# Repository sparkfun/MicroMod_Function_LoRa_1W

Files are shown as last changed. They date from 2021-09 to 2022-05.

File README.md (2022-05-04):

SparkFun MicroMod LoRa Function Board
========================================

SparkFun MicroMod LoRa Function Board (https://www.sparkfun.com/products/18573)

[*SparkFun MicroMod LoRa Function Board (DEV-18573)*](https://www.sparkfun.com/products/18573)

The SparkFun MicroMod LoRa Function Board provides LoRA and LoRaWAN capabilities to your MicroMod project. It is intended to be used in conjunction with a MicroMod Processor Board and a MicroMod Main Board, which provides the electrical interface between a processor board and the Function Board(s).

The LoRa Function Board utilizes the 915M30S LoRa module from EBYTE, which is a 1W (30dBm) transceiver based around the SX1276 from Semtech. There is a robust edge mount RP-SMA connector for large LoRa (915MHz) antennas; with modification, a U.FL connector is also available. We've successfully tested a 12 miles line-of-sight transmission with this module (test was performed under ideal conditions; individual user results may vary).

With the MicroMod standardization, users no longer need to cross-reference schematics with datasheets, while fumbling around with jumper wires. Simply, match up the function board's M.2 edge connector to the slot of the M.2 connector on the main board and secure the function board with screws.

Repository Contents
-------------------

* **/Firmware** - Arduino example code from the tutorial
* **/Hardware** - Eagle design files (.brd, .sch)
* **/Hardware/Production** - Production panel files (.brd)

Documentation
--------------

* **[E19-915M30S Datasheet](https://github.com/sparkfun/MicroMod_Function_LoRa_1W/blob/main/Documents/E19-915M30S_Usermanual_EN_v1.20.pdf)** - Datasheet for the LoRa module
  * **[SX1276 Datasheet](https://cdn.sparkfun.com/assets/7/7/3/2/2/SX1276_Datasheet.pdf)** - Datasheet for the transceiver the LoRa module is based on
* **[Hookup Guide](https://learn.sparkfun.com/tutorials/1996)** - Basic hookup guide
* **[SparkFun External EEPROM Arduino Library](https://github.com/sparkfun/SparkFun_External_EEPROM_Arduino_Library)** - Arduino library for the EEPROM
* **[RadioLib Arduino Library](https://github.com/jgromes/RadioLib)** - Arduino library for peer-to-peer communication with the LoRa module

Product Versions
----------------

* [DEV-18573](https://www.sparkfun.com/products/18573)- Initial release

Version History
---------------

* v1.0 - Initial Release

License Information
-------------------

This product is _**open source**_! 

Please review the LICENSE.md file for license information. 

If you have any questions or concerns on licensing, please contact technical support on our [SparkFun forums](https://forum.sparkfun.com/viewforum.php?f=152).

Distributed as-is; no warranty is given.

- Your friends at SparkFun.

_<COLLABORATION CREDIT>_

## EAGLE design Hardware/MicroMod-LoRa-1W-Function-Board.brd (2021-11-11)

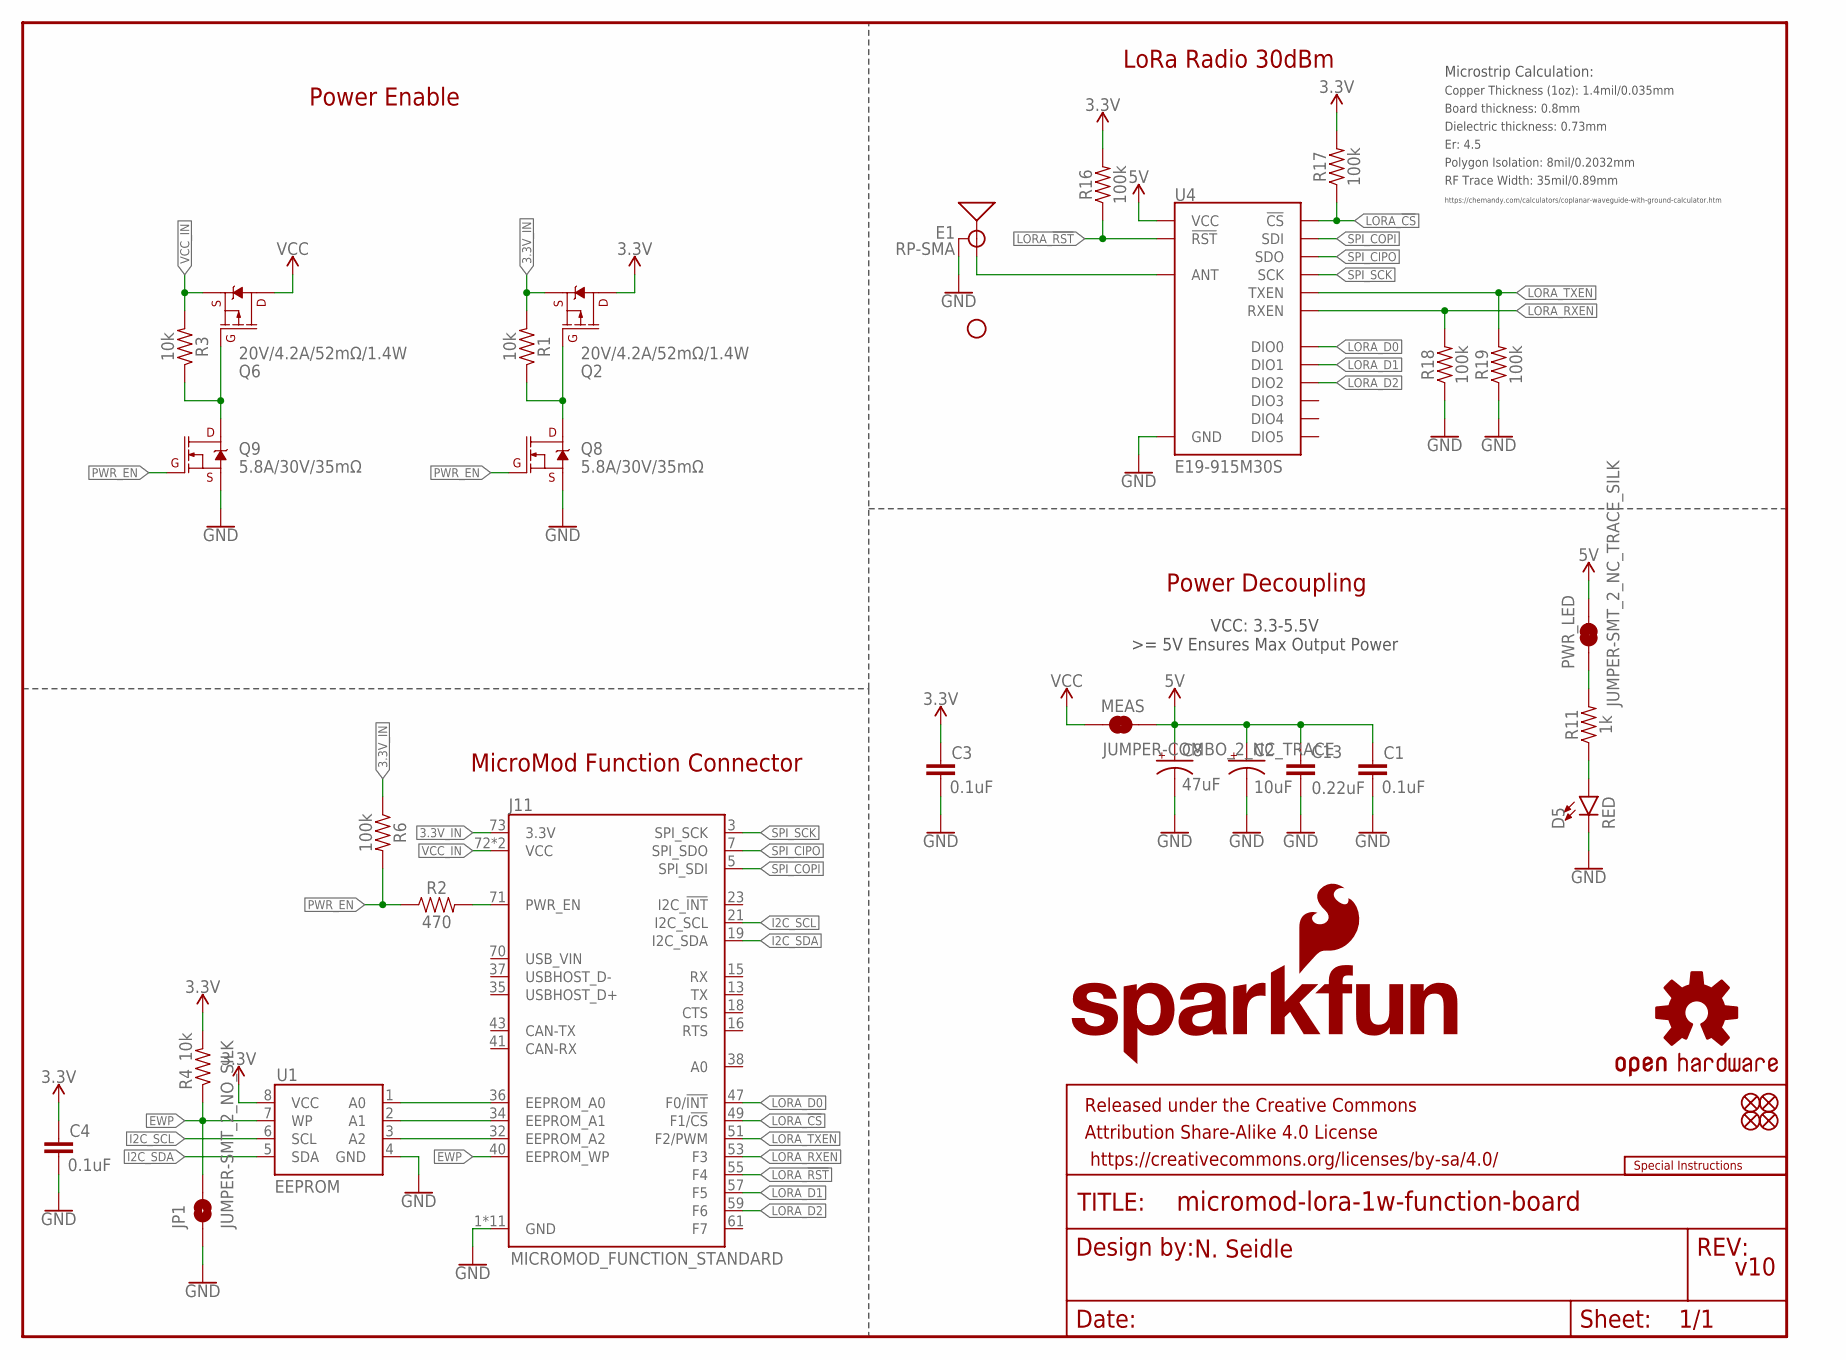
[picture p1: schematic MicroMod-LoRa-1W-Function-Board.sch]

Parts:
C1, C3, C4: 0.1uF; 0603
C2: 10uF; EIA3216
C8: 47uF; EIA3528
C13: 0.22uF; 0603
D5: RED; LED-0603
E1: RP-SMA; SMA-EDGE-SMD
FD1, FD2, FD3, FD4: FIDUCIALUFIDUCIAL; FIDUCIAL-MICRO
FRAME2: FRAME-LETTER; CREATIVE_COMMONS
H1: STAND-OFF
J11: MICROMOD_FUNCTION_STANDARD; M.2-CARD-E-22_FUNCTION_STANDARD
JP1: JUMPER-SMT_2_NO_SILK; SMT-JUMPER_2_NO_SILK
LOGO1: SFE_LOGO_NAME_FLAME.1_INCH; SFE_LOGO_NAME_FLAME_.1
LOGO2: SPECIAL_INSTRUCTIONS-ORDERING; ORDERING_INSTRUCTIONS
LOGO3: OSHW-LOGOMINI; OSHW-LOGO-MINI
MEAS: JUMPER-COMBO_2_NC_TRACE; COMBO-JUMPER_2_NC_TRACE
PWR_LED: JUMPER-SMT_2_NC_TRACE_SILK; SMT-JUMPER_2_NC_TRACE_SILK
Q2, Q6: 20V/4.2A/52mΩ/1.4W; SOT23-3
Q8, Q9: 5.8A/30V/35mΩ; SOT23-3
R1, R3, R4: 10k; 0603
R2: 470; 0603
R6, R16, R17, R18, R19: 100k; 0603
R11: 1k; 0603
U1: EEPROM; SO08
U4: E19-915M30S; E19-915MS1W

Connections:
3.3V: C3.1, C4.1, Q2.3 (D), R4.2, R16.2, R17.2, U1.8 (VCC)
3.3V_IN: J11.73 (3.3V), Q2.2 (S), R1.2, R6.1
5V: C1.1, C2.+, C8.A (+), C13.1, MEAS.2, MEAS.4 (2), PWR_LED.2, U4.11 (VCC)
A0: J11.36 (EEPROM_A0), U1.1 (A0)
A1: J11.34 (EEPROM_A1), U1.2 (A1)
A2: J11.32 (EEPROM_A2), U1.3 (A2)
EWP: J11.40 (EEPROM_WP), JP1.2, R4.1, U1.7 (WP)
GND: C1.2, C2.-, C3.2, C4.2, C8.C (-), C13.2, D5.C, E1.GND@0 (GND), E1.GND@1 (GND), J11.1 (GND), J11.33 (GND), J11.39 (GND), J11.45 (GND), J11.75 (GND), J11.GND1 (GND), J11.GND2 (GND), J11.GND3 (GND), J11.GND4 (GND), J11.GND5 (GND), J11.GND6 (GND), JP1.1, Q8.2 (S), Q9.2 (S), R18.1, R19.1, U1.4 (GND), U4.1 (GND), U4.9 (GND), U4.10 (GND), U4.18 (GND), U4.20 (GND), U4.21 (GND), U4.22 (GND)
I2C_SCL: J11.21 (I2C_SCL), U1.6 (SCL)
I2C_SDA: J11.19 (I2C_SDA), U1.5 (SDA)
LORA_!CS!: J11.49 (F1/!CS!), R17.1, U4.15 (!CS)
LORA_!RST!: J11.55 (F4), R16.1, U4.8 (!RST)
LORA_D0: J11.47 (F0/!INT!), U4.7 (DIO0)
LORA_D1: J11.57 (F5), U4.6 (DIO1)
LORA_D2: J11.59 (F6), U4.5 (DIO2)
LORA_RXEN: J11.53 (F3), R18.2, U4.17 (RXEN)
LORA_TXEN: J11.51 (F2/PWM), R19.2, U4.16 (TXEN)
unnamed: E1.SIG (SIGNAL), U4.19 (ANT)
unnamed: Q2.1 (G), Q8.3 (D), R1.1
unnamed: Q6.1 (G), Q9.3 (D), R3.1
unnamed: J11.71 (PWR_EN), R2.2
unnamed: D5.A, R11.1
unnamed: PWR_LED.1, R11.2
PWR_EN: Q8.1 (G), Q9.1 (G), R2.1, R6.2
SPI_CIPO: J11.7 (SPI_SDO), U4.13 (SDO)
SPI_COPI: J11.5 (SPI_SDI), U4.14 (SDI)
SPI_SCK: J11.3 (SPI_SCK), U4.12 (SCK)
VCC: MEAS.1, MEAS.3 (1), Q6.3 (D)
VCC_IN: J11.72 (VCC), J11.74 (VCC), Q6.2 (S), R3.2

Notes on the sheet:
Power Decoupling
MicroMod Function Connector
VCC: 3.3-5.5V >= 5V Ensures Max Output Power
N. Seidle
v10
LoRa Radio 30dBm
Board thickness: 0.8mm
Er: 4.5
Copper Thickness (1oz): 1.4mil/0.035mm
RF Trace Width: 35mil/0.89mm
Polygon Isolation: 8mil/0.2032mm
Dielectric thickness: 0.73mm
https://chemandy.com/calculators/coplanar-waveguide-with-ground-calculator.htm
Microstrip Calculation:
Power Enable

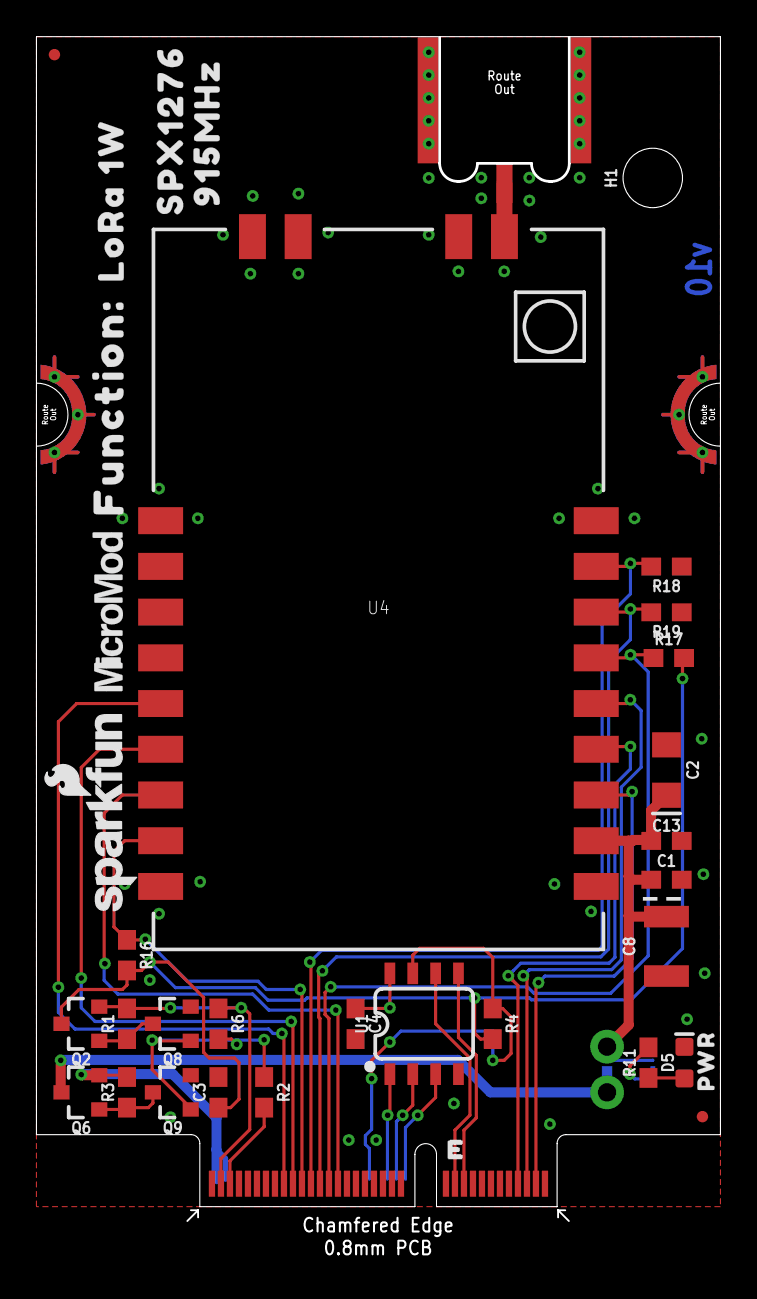
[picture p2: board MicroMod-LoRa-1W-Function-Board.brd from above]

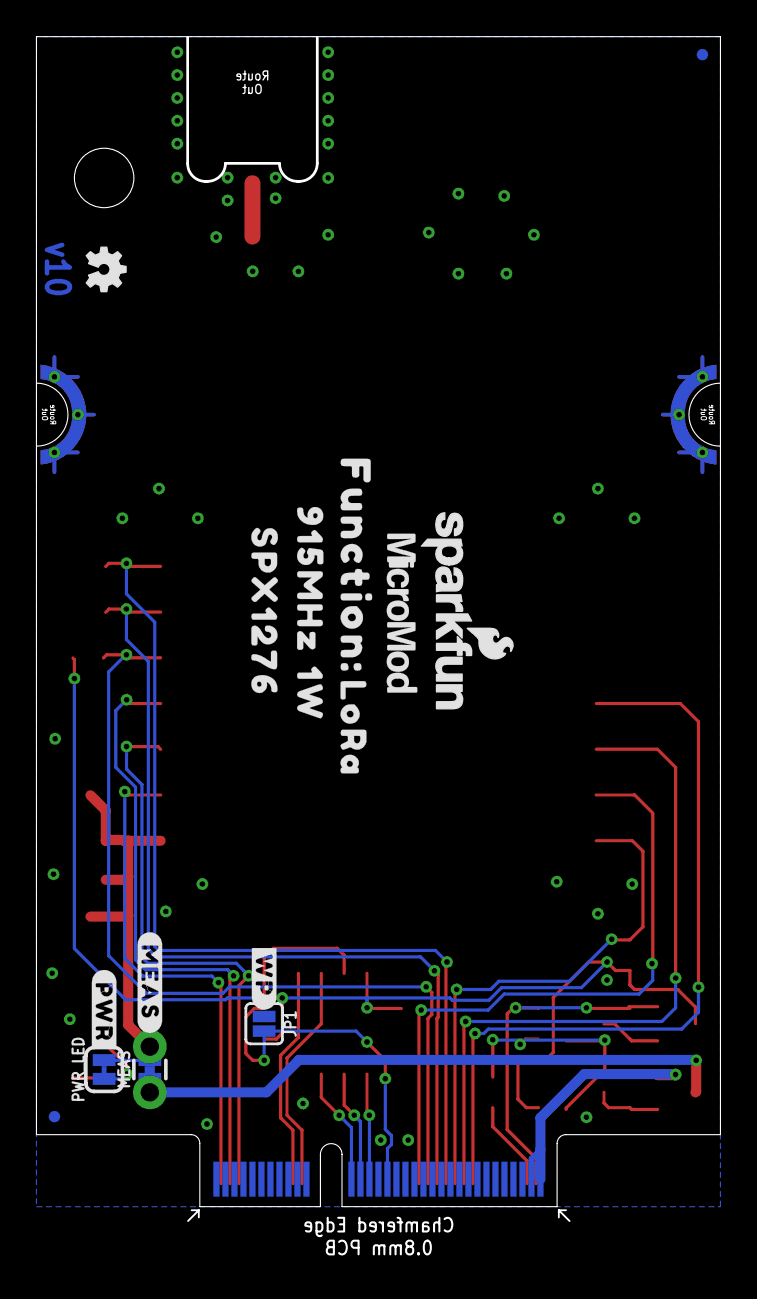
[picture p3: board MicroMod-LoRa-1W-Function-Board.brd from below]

Board: 2 copper layers, 38.0 x 65.8 mm, 54 parts (16 on the bottom side), 29 nets.

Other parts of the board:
LOGO4: SFE_LOGO_NAME_FLAME.1_INCH; SFE_LOGO_NAME_FLAME_.1
U$1, U$5: LORA0
U$2, U$30: 1W1
U$3, U$29: 915MHZ2
U$4, U$8: FUNCTION#0
U$6, U$27: SPX12763
U$7: PWR0
U$9: #PWR#0
U$10: #WP#0
U$28: #MEAS#3
U$37, U$63: MICROMOD_LOGO_.35

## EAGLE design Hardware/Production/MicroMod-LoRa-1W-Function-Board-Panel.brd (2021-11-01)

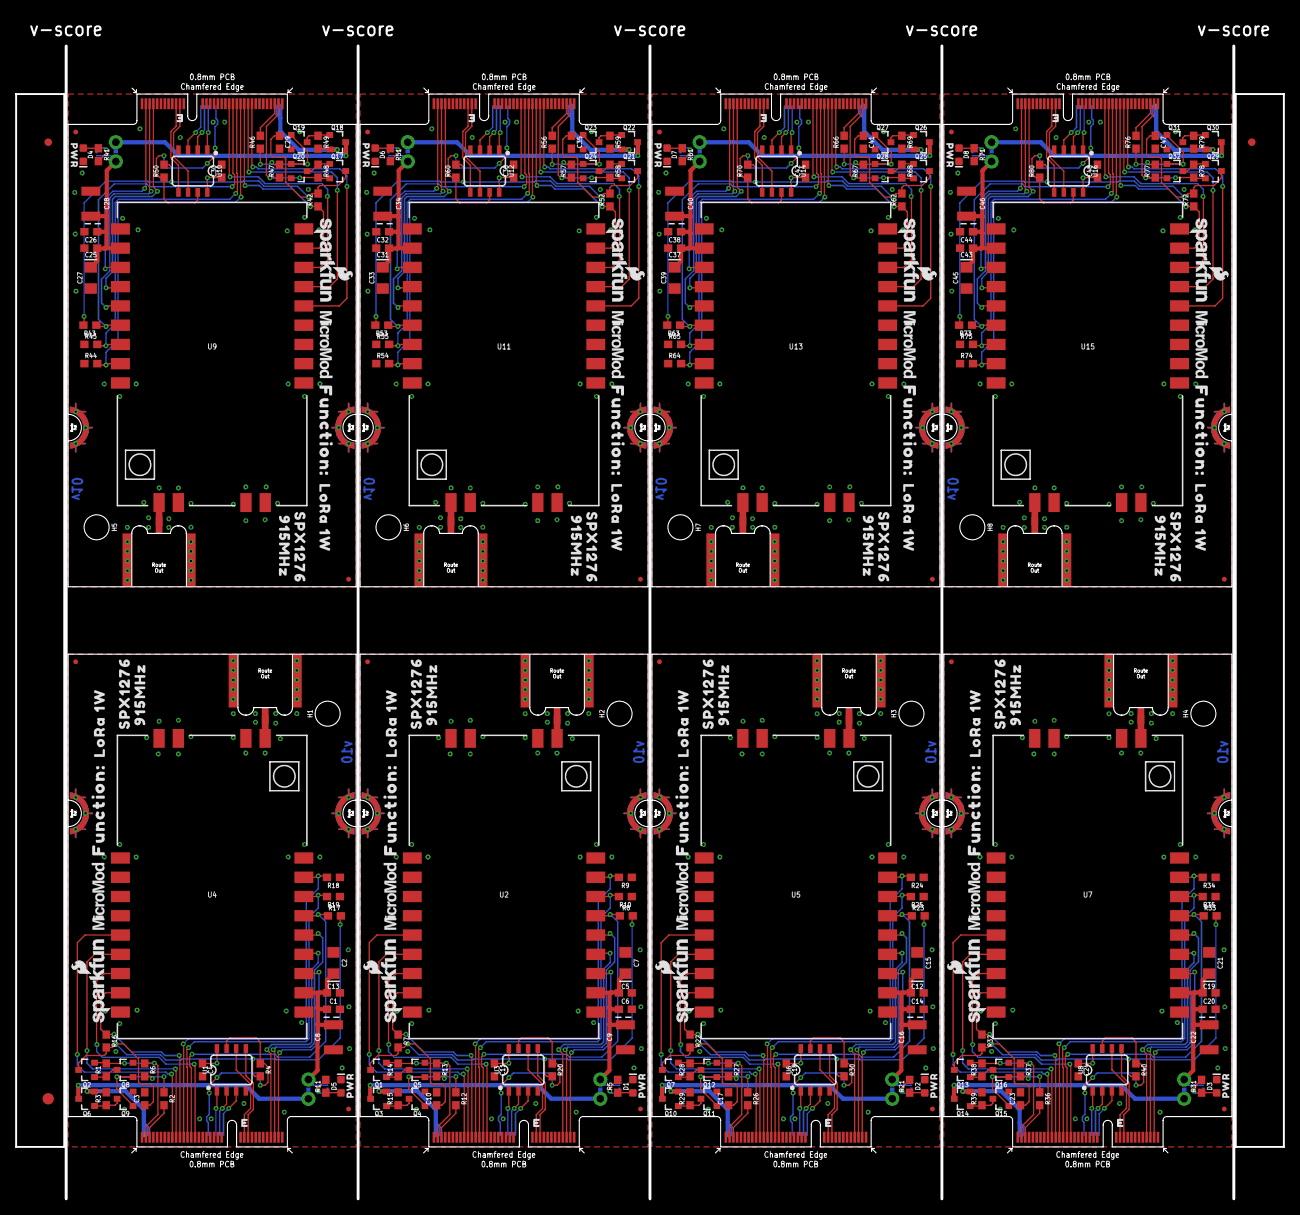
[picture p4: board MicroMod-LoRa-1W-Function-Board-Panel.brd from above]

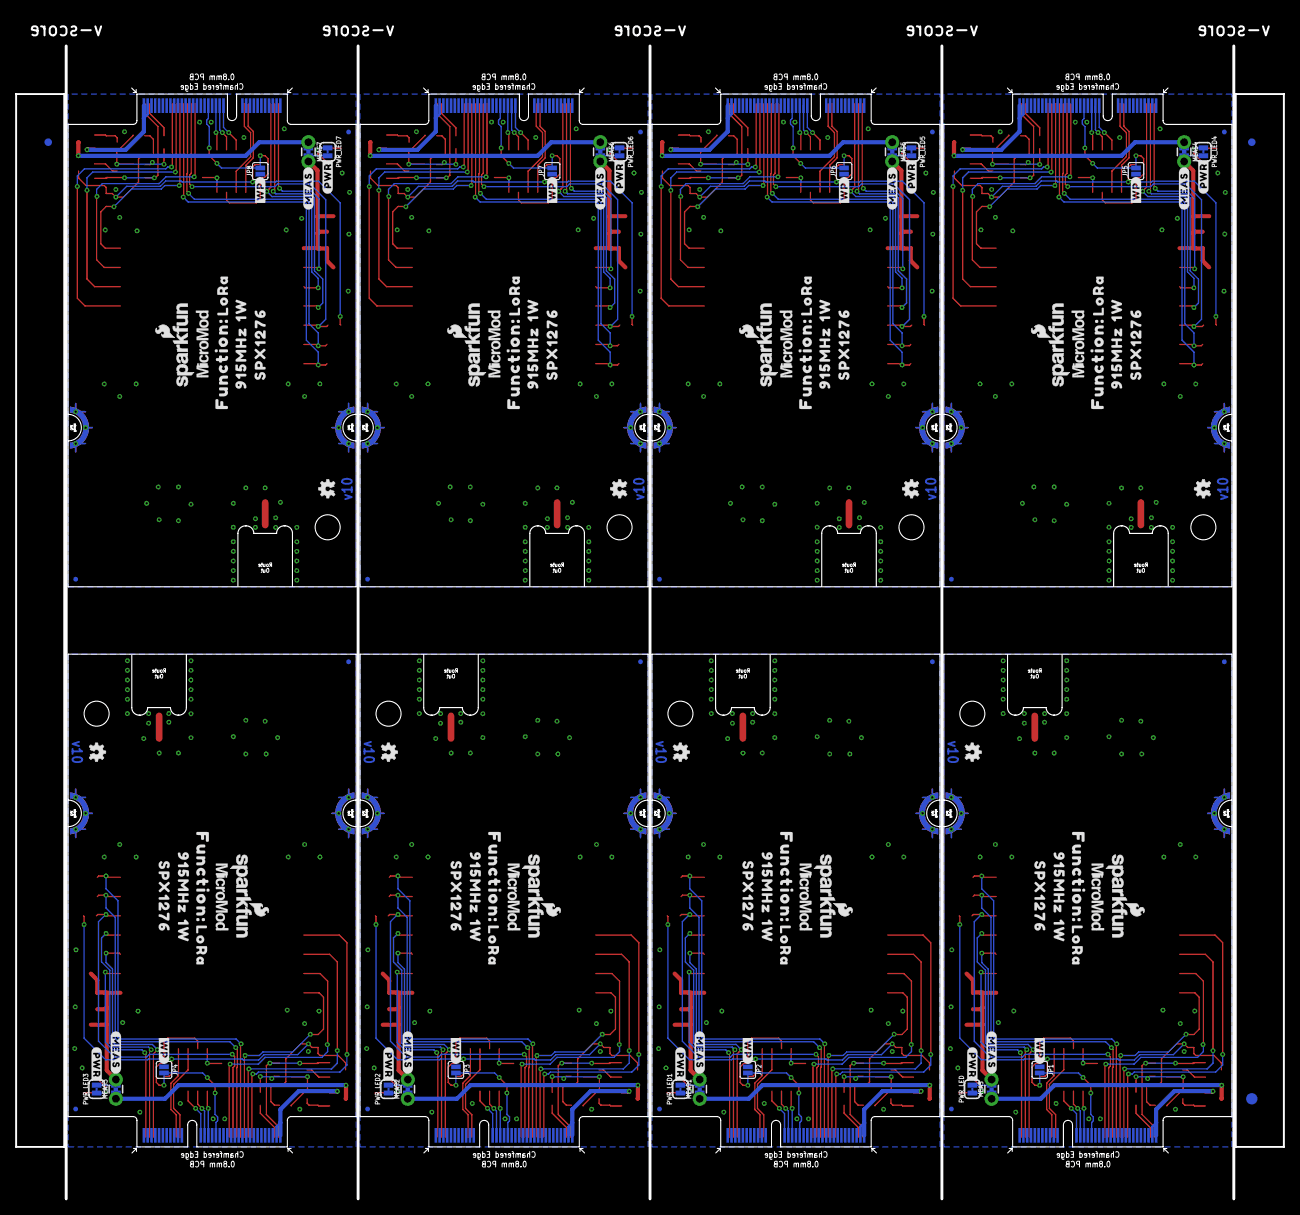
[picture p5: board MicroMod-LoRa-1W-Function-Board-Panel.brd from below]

Board: 2 copper layers, 167.2 x 152.1 mm, 422 parts (131 on the bottom side), 232 nets.

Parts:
C1, C3, C4, C6, C10, C11, C14, C17, C18, C20, C23, C24, C26, C29, C30, C32, C35, C36, C38, C41, C42, C44, C47, C48: 0.1uF; 0603
C2, C7, C15, C21, C27, C33, C39, C45: 10uF; EIA3216
C5, C12, C13, C19, C25, C31, C37, C43: 0.22uF; 0603
C8, C9, C16, C22, C28, C34, C40, C46: 47uF; EIA3528
D1, D2, D3, D4, D5, D6, D7, D8: RED; LED-0603
E1, E2, E3, E4, E5, E6, E7, E8: RP-SMA; SMA-EDGE-SMD
E$1, E$2, E$3, E$4: FIDUCIAL-1X2
E$5, E$6: FIDUCIAL-1.5X3
FD1, FD2, FD3, FD4, FD5, FD6, FD7, FD8, FD9, FD10, FD11, FD12, FD13, FD14, FD15, FD16, FD17, FD18, FD19, FD20, FD21, FD22, FD23, FD24, FD25, FD26, FD27, FD28, FD29, FD30, FD31, FD32: FIDUCIALUFIDUCIAL; FIDUCIAL-MICRO
H1, H2, H3, H4, H5, H6, H7, H8: STAND-OFF
J1, J2, J3, J4, J5, J6, J7, J11: MICROMOD_STANDARD; M.2-CARD-E-22_FUNCTION_STANDARD
JP1, JP2, JP3, JP4, JP5, JP6, JP7, JP8: JUMPER-SMT_2_NO_SILK; SMT-JUMPER_2_NO_SILK
LOGO1, LOGO2, LOGO4, LOGO6, LOGO7, LOGO9, LOGO10, LOGO12, LOGO13, LOGO15, LOGO16, LOGO18, LOGO19, LOGO21, LOGO22, LOGO24: SFE_LOGO_NAME_FLAME.1_INCH; SFE_LOGO_NAME_FLAME_.1
LOGO3, LOGO5, LOGO8, LOGO11, LOGO14, LOGO17, LOGO20, LOGO23: OSHW-LOGOMINI; OSHW-LOGO-MINI
MEAS, MEAS1, MEAS2, MEAS3, MEAS4, MEAS5, MEAS6, MEAS7: JUMPER-COMBO_2_NC_TRACE; COMBO-JUMPER_2_NC_TRACE
PWR_LED, PWR_LED1, PWR_LED2, PWR_LED3, PWR_LED4, PWR_LED5, PWR_LED6, PWR_LED7: JUMPER-SMT_2_NC_TRACE_SILK; SMT-JUMPER_2_NC_TRACE_SILK
Q1, Q2, Q3, Q6, Q7, Q10, Q13, Q14, Q17, Q18, Q21, Q22, Q25, Q26, Q29, Q30: 20V/4.2A/52mΩ/1.4W; SOT23-3
Q4, Q5, Q8, Q9, Q11, Q12, Q15, Q16, Q19, Q20, Q23, Q24, Q27, Q28, Q31, Q32: 5.8A/30V/35mΩ; SOT23-3
R1, R3, R4, R14, R15, R20, R28, R29, R30, R38, R39, R40, R48, R49, R50, R58, R59, R60, R68, R69, R70, R78, R79, R80: 10k; 0603
R2, R12, R26, R36, R46, R56, R66, R76: 470; 0603
R5, R11, R21, R31, R41, R51, R61, R71: 1k; 0603
R6, R7, R8, R9, R10, R13, R16, R17, R18, R19, R22, R23, R24, R25, R27, R32, R33, R34, R35, R37, R42, R43, R44, R45, R47, R52, R53, R54, R55, R57, R62, R63, R64, R65, R67, R72, R73, R74, R75, R77: 100k; 0603
U1, U3, U6, U8, U10, U12, U14, U16: EEPROM; SO08
U2, U4, U5, U7, U9, U11, U13, U15: E19-915M30S; E19-915MS1W
U$1, U$5, U$16, U$19, U$36, U$40, U$53, U$56, U$70, U$73, U$86, U$89, U$102, U$105, U$118, U$121: LORA0
U$2, U$14, U$22, U$30, U$34, U$43, U$51, U$59, U$68, U$76, U$84, U$92, U$100, U$108, U$116, U$124: 1W1
U$3, U$15, U$21, U$29, U$35, U$42, U$52, U$58, U$69, U$75, U$85, U$91, U$101, U$107, U$117, U$123: 915MHZ2
U$4, U$8, U$23, U$25, U$44, U$46, U$60, U$62, U$77, U$79, U$93, U$95, U$109, U$111, U$125, U$127: FUNCTION#0
U$6, U$17, U$20, U$27, U$38, U$41, U$54, U$57, U$71, U$74, U$87, U$90, U$103, U$106, U$119, U$122: SPX12763
U$7, U$18, U$39, U$55, U$72, U$88, U$104, U$120: PWR0
U$9, U$24, U$45, U$61, U$78, U$94, U$110, U$126: #PWR#0
U$10, U$26, U$47, U$64, U$80, U$96, U$112, U$128: #WP#0
U$11, U$12, U$31, U$32, U$37, U$48, U$49, U$63, U$65, U$66, U$81, U$82, U$97, U$98, U$113, U$114: MICROMOD_LOGO_.35
U$13, U$28, U$33, U$50, U$67, U$83, U$99, U$115: #MEAS#3

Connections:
3.3V: C3.1, C4.1, Q2.3, R4.2, R16.2, R17.2, U1.8
3.3V1: C10.1, C11.1, Q1.3, R7.2, R8.2, R20.2, U3.8
3.3V2: C17.1, C18.1, Q7.3, R22.2, R23.2, R30.2, U6.8
3.3V3: C23.1, C24.1, Q13.3, R32.2, R33.2, R40.2, U8.8
3.3V4: C29.1, C30.1, Q17.3, R42.2, R43.2, R50.2, U10.8
3.3V5: C35.1, C36.1, Q21.3, R52.2, R53.2, R60.2, U12.8
3.3V6: C41.1, C42.1, Q25.3, R62.2, R63.2, R70.2, U14.8
3.3V7: C47.1, C48.1, Q29.3, R72.2, R73.2, R80.2, U16.8
3.3V_IN: J11.73, Q2.2, R1.2, R6.1
3.3V_IN1: J1.73, Q1.2, R13.1, R14.2
3.3V_IN2: J2.73, Q7.2, R27.1, R28.2
3.3V_IN3: J3.73, Q13.2, R37.1, R38.2
3.3V_IN4: J4.73, Q17.2, R47.1, R48.2
3.3V_IN5: J5.73, Q21.2, R57.1, R58.2
3.3V_IN6: J6.73, Q25.2, R67.1, R68.2
3.3V_IN7: J7.73, Q29.2, R77.1, R78.2
5V: C1.1, C2.+, C8.A, C13.1, MEAS.2, MEAS.4, PWR_LED.2, U4.11
5V1: C5.1, C6.1, C7.+, C9.A, MEAS1.2, MEAS1.4, PWR_LED1.2, U2.11
5V2: C12.1, C14.1, C15.+, C16.A, MEAS2.2, MEAS2.4, PWR_LED2.2, U5.11
5V3: C19.1, C20.1, C21.+, C22.A, MEAS3.2, MEAS3.4, PWR_LED3.2, U7.11
5V4: C25.1, C26.1, C27.+, C28.A, MEAS4.2, MEAS4.4, PWR_LED4.2, U9.11
5V5: C31.1, C32.1, C33.+, C34.A, MEAS5.2, MEAS5.4, PWR_LED5.2, U11.11
5V6: C37.1, C38.1, C39.+, C40.A, MEAS6.2, MEAS6.4, PWR_LED6.2, U13.11
5V7: C43.1, C44.1, C45.+, C46.A, MEAS7.2, MEAS7.4, PWR_LED7.2, U15.11
A0: J11.36, U1.1
A1: J11.34, U1.2
A2: J11.32, U1.3
A3: J1.36, U3.1
A4: J1.32, U3.3
A5: J1.34, U3.2
A6: J2.36, U6.1
A7: J2.32, U6.3
A8: J2.34, U6.2
A9: J3.36, U8.1
A10: J3.32, U8.3
A11: J3.34, U8.2
A12: J4.36, U10.1
A13: J4.32, U10.3
A14: J4.34, U10.2
A15: J5.36, U12.1
A16: J5.32, U12.3
A17: J5.34, U12.2
A18: J6.36, U14.1
A19: J6.32, U14.3
A20: J6.34, U14.2
A21: J7.36, U16.1
A22: J7.32, U16.3
A23: J7.34, U16.2
EWP: J11.40, JP1.2, R4.1, U1.7
EWP1: J1.40, JP2.2, R20.1, U3.7
EWP2: J2.40, JP3.2, R30.1, U6.7
EWP3: J3.40, JP4.2, R40.1, U8.7
EWP4: J4.40, JP5.2, R50.1, U10.7
EWP5: J5.40, JP6.2, R60.1, U12.7
EWP6: J6.40, JP7.2, R70.1, U14.7
EWP7: J7.40, JP8.2, R80.1, U16.7
GND: C1.2, C2.-, C3.2, C4.2, C8.C, C13.2, D5.C, E1.GND@0, E1.GND@1, J11.1, J11.33, J11.39, J11.45, J11.75, J11.GND1, J11.GND2, J11.GND3, J11.GND4, J11.GND5, J11.GND6, JP1.1, Q8.2, Q9.2, R18.1, R19.1, U1.4, U4.1, U4.9, U4.10, U4.18, U4.20, U4.21, U4.22
GND1: C5.2, C6.2, C7.-, C9.C, C10.2, C11.2, D1.C, E2.GND@0, E2.GND@1, J1.1, J1.33, J1.39, J1.45, J1.75, J1.GND1, J1.GND2, J1.GND3, J1.GND4, J1.GND5, J1.GND6, JP2.1, Q4.2, Q5.2, R9.1, R10.1, U2.1, U2.9, U2.10, U2.18, U2.20, U2.21, U2.22, U3.4
GND2: C12.2, C14.2, C15.-, C16.C, C17.2, C18.2, D2.C, E3.GND@0, E3.GND@1, J2.1, J2.33, J2.39, J2.45, J2.75, J2.GND1, J2.GND2, J2.GND3, J2.GND4, J2.GND5, J2.GND6, JP3.1, Q11.2, Q12.2, R24.1, R25.1, U5.1, U5.9, U5.10, U5.18, U5.20, U5.21, U5.22, U6.4
GND3: C19.2, C20.2, C21.-, C22.C, C23.2, C24.2, D3.C, E4.GND@0, E4.GND@1, J3.1, J3.33, J3.39, J3.45, J3.75, J3.GND1, J3.GND2, J3.GND3, J3.GND4, J3.GND5, J3.GND6, JP4.1, Q15.2, Q16.2, R34.1, R35.1, U7.1, U7.9, U7.10, U7.18, U7.20, U7.21, U7.22, U8.4
GND4: C25.2, C26.2, C27.-, C28.C, C29.2, C30.2, D4.C, E5.GND@0, E5.GND@1, J4.1, J4.33, J4.39, J4.45, J4.75, J4.GND1, J4.GND2, J4.GND3, J4.GND4, J4.GND5, J4.GND6, JP5.1, Q19.2, Q20.2, R44.1, R45.1, U9.1, U9.9, U9.10, U9.18, U9.20, U9.21, U9.22, U10.4
GND5: C31.2, C32.2, C33.-, C34.C, C35.2, C36.2, D6.C, E6.GND@0, E6.GND@1, J5.1, J5.33, J5.39, J5.45, J5.75, J5.GND1, J5.GND2, J5.GND3, J5.GND4, J5.GND5, J5.GND6, JP6.1, Q23.2, Q24.2, R54.1, R55.1, U11.1, U11.9, U11.10, U11.18, U11.20, U11.21, U11.22, U12.4
GND6: C37.2, C38.2, C39.-, C40.C, C41.2, C42.2, D7.C, E7.GND@0, E7.GND@1, J6.1, J6.33, J6.39, J6.45, J6.75, J6.GND1, J6.GND2, J6.GND3, J6.GND4, J6.GND5, J6.GND6, JP7.1, Q27.2, Q28.2, R64.1, R65.1, U13.1, U13.9, U13.10, U13.18, U13.20, U13.21, U13.22, U14.4
GND7: C43.2, C44.2, C45.-, C46.C, C47.2, C48.2, D8.C, E8.GND@0, E8.GND@1, J7.1, J7.33, J7.39, J7.45, J7.75, J7.GND1, J7.GND2, J7.GND3, J7.GND4, J7.GND5, J7.GND6, JP8.1, Q31.2, Q32.2, R74.1, R75.1, U15.1, U15.9, U15.10, U15.18, U15.20, U15.21, U15.22, U16.4
I2C_SCL: J11.21, U1.6
I2C_SCL1: J1.21, U3.6
I2C_SCL2: J2.21, U6.6
I2C_SCL3: J3.21, U8.6
I2C_SCL4: J4.21, U10.6
I2C_SCL5: J5.21, U12.6
I2C_SCL6: J6.21, U14.6
I2C_SCL7: J7.21, U16.6
I2C_SDA: J11.19, U1.5
I2C_SDA1: J1.19, U3.5
I2C_SDA2: J2.19, U6.5
I2C_SDA3: J3.19, U8.5
I2C_SDA4: J4.19, U10.5
I2C_SDA5: J5.19, U12.5
I2C_SDA6: J6.19, U14.5
I2C_SDA7: J7.19, U16.5
LORA_!CS!: J11.49, R17.1, U4.15
LORA_!CS!1: J1.49, R8.1, U2.15
LORA_!CS!2: J2.49, R23.1, U5.15
LORA_!CS!3: J3.49, R33.1, U7.15
LORA_!CS!4: J4.49, R43.1, U9.15
LORA_!CS!5: J5.49, R53.1, U11.15
LORA_!CS!6: J6.49, R63.1, U13.15
LORA_!CS!7: J7.49, R73.1, U15.15
LORA_!RST!: J11.55, R16.1, U4.8
LORA_!RST!1: J1.55, R7.1, U2.8
LORA_!RST!2: J2.55, R22.1, U5.8
LORA_!RST!3: J3.55, R32.1, U7.8
LORA_!RST!4: J4.55, R42.1, U9.8
LORA_!RST!5: J5.55, R52.1, U11.8
LORA_!RST!6: J6.55, R62.1, U13.8
LORA_!RST!7: J7.55, R72.1, U15.8
LORA_D0: J11.47, U4.7
LORA_D1: J11.57, U4.6
LORA_D2: J11.59, U4.5
LORA_D3: J1.47, U2.7
LORA_D4: J1.57, U2.6
LORA_D5: J1.59, U2.5
LORA_D6: J2.47, U5.7
LORA_D7: J2.57, U5.6
LORA_D8: J2.59, U5.5
LORA_D9: J3.47, U7.7
LORA_D10: J3.57, U7.6
LORA_D11: J3.59, U7.5
LORA_D12: J4.47, U9.7
LORA_D13: J4.57, U9.6
LORA_D14: J4.59, U9.5
LORA_D15: J5.47, U11.7
LORA_D16: J5.57, U11.6
LORA_D17: J5.59, U11.5
LORA_D18: J6.47, U13.7
LORA_D19: J6.57, U13.6
LORA_D20: J6.59, U13.5
LORA_D21: J7.47, U15.7
LORA_D22: J7.57, U15.6
LORA_D23: J7.59, U15.5
LORA_RXEN: J11.53, R18.2, U4.17
LORA_RXEN1: J1.53, R9.2, U2.17
LORA_RXEN2: J2.53, R24.2, U5.17
LORA_RXEN3: J3.53, R34.2, U7.17
LORA_RXEN4: J4.53, R44.2, U9.17
LORA_RXEN5: J5.53, R54.2, U11.17
LORA_RXEN6: J6.53, R64.2, U13.17
LORA_RXEN7: J7.53, R74.2, U15.17
LORA_TXEN: J11.51, R19.2, U4.16
LORA_TXEN1: J1.51, R10.2, U2.16
LORA_TXEN2: J2.51, R25.2, U5.16
LORA_TXEN3: J3.51, R35.2, U7.16
LORA_TXEN4: J4.51, R45.2, U9.16
LORA_TXEN5: J5.51, R55.2, U11.16
LORA_TXEN6: J6.51, R65.2, U13.16
LORA_TXEN7: J7.51, R75.2, U15.16
unnamed: E1.SIG, U4.19
unnamed: Q2.1, Q8.3, R1.1
unnamed: Q6.1, Q9.3, R3.1
unnamed: J11.71, R2.2
unnamed: D5.A, R11.1
unnamed: PWR_LED.1, R11.2
unnamed: PWR_LED1.1, R5.2
unnamed: D1.A, R5.1
unnamed: E2.SIG, U2.19
unnamed: J1.71, R12.2
unnamed: Q1.1, Q5.3, R14.1
unnamed: Q3.1, Q4.3, R15.1
unnamed: PWR_LED2.1, R21.2
unnamed: D2.A, R21.1
unnamed: E3.SIG, U5.19
unnamed: J2.71, R26.2
unnamed: Q7.1, Q12.3, R28.1
unnamed: Q10.1, Q11.3, R29.1
unnamed: PWR_LED3.1, R31.2
unnamed: D3.A, R31.1
unnamed: E4.SIG, U7.19
unnamed: J3.71, R36.2
unnamed: Q13.1, Q16.3, R38.1
unnamed: Q14.1, Q15.3, R39.1
unnamed: PWR_LED4.1, R41.2
unnamed: D4.A, R41.1
unnamed: E5.SIG, U9.19
unnamed: J4.71, R46.2
unnamed: Q17.1, Q20.3, R48.1
unnamed: Q18.1, Q19.3, R49.1
unnamed: PWR_LED5.1, R51.2
unnamed: D6.A, R51.1
unnamed: E6.SIG, U11.19
unnamed: J5.71, R56.2
unnamed: Q21.1, Q24.3, R58.1
unnamed: Q22.1, Q23.3, R59.1
unnamed: PWR_LED6.1, R61.2
unnamed: D7.A, R61.1
unnamed: E7.SIG, U13.19
unnamed: J6.71, R66.2
unnamed: Q25.1, Q28.3, R68.1
unnamed: Q26.1, Q27.3, R69.1
unnamed: PWR_LED7.1, R71.2
unnamed: D8.A, R71.1
unnamed: E8.SIG, U15.19
unnamed: J7.71, R76.2
unnamed: Q29.1, Q32.3, R78.1
unnamed: Q30.1, Q31.3, R79.1
PWR_EN: Q8.1, Q9.1, R2.1, R6.2
PWR_EN1: Q4.1, Q5.1, R12.1, R13.2
PWR_EN2: Q11.1, Q12.1, R26.1, R27.2
PWR_EN3: Q15.1, Q16.1, R36.1, R37.2
PWR_EN4: Q19.1, Q20.1, R46.1, R47.2
PWR_EN5: Q23.1, Q24.1, R56.1, R57.2
PWR_EN6: Q27.1, Q28.1, R66.1, R67.2
PWR_EN7: Q31.1, Q32.1, R76.1, R77.2
SPI_CIPO: J11.7, U4.13
SPI_CIPO1: J1.7, U2.13
SPI_CIPO2: J2.7, U5.13
SPI_CIPO3: J3.7, U7.13
SPI_CIPO4: J4.7, U9.13
SPI_CIPO5: J5.7, U11.13
SPI_CIPO6: J6.7, U13.13
SPI_CIPO7: J7.7, U15.13
SPI_COPI: J11.5, U4.14
SPI_COPI1: J1.5, U2.14
SPI_COPI2: J2.5, U5.14
SPI_COPI3: J3.5, U7.14
SPI_COPI4: J4.5, U9.14
SPI_COPI5: J5.5, U11.14
SPI_COPI6: J6.5, U13.14
SPI_COPI7: J7.5, U15.14
SPI_SCK: J11.3, U4.12
SPI_SCK1: J1.3, U2.12
SPI_SCK2: J2.3, U5.12
SPI_SCK3: J3.3, U7.12
SPI_SCK4: J4.3, U9.12
SPI_SCK5: J5.3, U11.12
SPI_SCK6: J6.3, U13.12
SPI_SCK7: J7.3, U15.12
VCC: MEAS.1, MEAS.3, Q6.3
VCC1: MEAS1.1, MEAS1.3, Q3.3
VCC2: MEAS2.1, MEAS2.3, Q10.3
VCC3: MEAS3.1, MEAS3.3, Q14.3
VCC4: MEAS4.1, MEAS4.3, Q18.3
VCC5: MEAS5.1, MEAS5.3, Q22.3
VCC6: MEAS6.1, MEAS6.3, Q26.3
VCC7: MEAS7.1, MEAS7.3, Q30.3
VCC_IN: J11.72, J11.74, Q6.2, R3.2
VCC_IN1: J1.72, J1.74, Q3.2, R15.2
VCC_IN2: J2.72, J2.74, Q10.2, R29.2
VCC_IN3: J3.72, J3.74, Q14.2, R39.2
VCC_IN4: J4.72, J4.74, Q18.2, R49.2
VCC_IN5: J5.72, J5.74, Q22.2, R59.2
VCC_IN6: J6.72, J6.74, Q26.2, R69.2
VCC_IN7: J7.72, J7.74, Q30.2, R79.2

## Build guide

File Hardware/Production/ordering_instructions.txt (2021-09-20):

panel size, 168x137mm
PCB thickness, 0.8mm
number of layers, 2
bevel, Gold Fingers + 45° Finger Chamfered
soldermask color, Red
silkscreen color, White
oz copper, 1oz
finish, ENIG
stencils, none
pcs per panel, 8
min trace width, 0.1778mm / 0.0070in
min drill size, 0.3048mm / 0.0120in

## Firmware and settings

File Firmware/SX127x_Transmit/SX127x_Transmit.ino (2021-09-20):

/*
  RadioLib SX1276 Transmit Example using the RFM97C 915MHz

  Gotchas:
      The RadioLib defaults the SX1276 to 434MHz so the reception is pretty
      poor. This is fixed with a radio.begin(915.0);
      The RadioLib really requires DIO0 and DIO1 be connected. Reset is optional.
      Avoid ESP pins 34/35/36/39 as they are inputs only
*/

#include <RadioLib.h> //Click here to get the library: http://librarymanager/All#RadioLib

int pin_powerEnable = 4;

// SX1276 has the following connections on the SparkFun MicroMod Artemis:
int pin_cs = 41;
int pin_dio0 = 0;
int pin_nrst = 33;
int pin_dio1 = 34;
SX1276 radio = new Module(pin_cs, pin_dio0, pin_nrst, pin_dio1);

void setup() {
  Serial.begin(115200);
  delay(500); //Wait for ESP32 to be able to print

  Serial.println("LOW");
  digitalWrite(pin_powerEnable, LOW);
  while (1);

  pinMode(pin_powerEnable, OUTPUT);
  Serial.println("HIGH");
  digitalWrite(pin_powerEnable, HIGH);
  while (1)
  {
    Serial.println("LOW");
    digitalWrite(pin_powerEnable, LOW);
    delay(2000);
    Serial.println("HIGH");
    digitalWrite(pin_powerEnable, HIGH);
    delay(2000);
  }

  Serial.print(F("[SX1276] Initializing ... "));
  //int state = radio.begin(); //-121dBm
  //int state = radio.begin(868.0); //-20dBm
  int state = radio.begin(915.0); //-23dBm
  if (state == ERR_NONE) {
    Serial.println(F("init success!"));
  } else {
    Serial.print(F("failed, code "));
    Serial.println(state);
    while (true);
  }

  // set output power to 10 dBm (accepted range is -3 - 17 dBm)
  // NOTE: 20 dBm value allows high power operation, but transmission
  //       duty cycle MUST NOT exceed 1%
  //  if (radio.setOutputPower(20) == ERR_INVALID_OUTPUT_POWER) {
  //    Serial.println(F("Selected output power is invalid for this module!"));
  //    while (true);
  //  }

  // some modules have an external RF switch
  // controlled via two pins (RX enable, TX enable)
  // to enable automatic control of the switch,
  // call the following method
  int pin_rx_enable = 16;
  int pin_tx_enable = 44;
  radio.setRfSwitchPins(pin_rx_enable, pin_tx_enable);
}

int counter = 0;

void loop() {
  Serial.print(F("[SX1276] Transmitting packet ... "));

  // you can transmit C-string or Arduino string up to
  // 256 characters long
  // NOTE: transmit() is a blocking method!
  //       See example SX127x_Transmit_Interrupt for details
  //       on non-blocking transmission method.

  char output[50];
  sprintf(output, "Counter: %d", counter++);

  int state = radio.transmit(output);

  // you can also transmit byte array up to 256 bytes long
  /*
    byte byteArr[] = {0x01, 0x23, 0x45, 0x67, 0x89, 0xAB, 0xCD, 0xEF};
    int state = radio.transmit(byteArr, 8);
  */

  if (state == ERR_NONE) {
    // the packet was successfully transmitted
    Serial.println(F(" success!"));

    // print measured data rate
    Serial.print(F("[SX1276] Datarate:\t"));
    Serial.print(radio.getDataRate());
    Serial.println(F(" bps"));

  } else if (state == ERR_PACKET_TOO_LONG) {
    // the supplied packet was longer than 256 bytes
    Serial.println(F("too long!"));

  } else if (state == ERR_TX_TIMEOUT) {
    // timeout occurred while transmitting packet
    Serial.println(F("timeout!"));

  } else {
    // some other error occurred
    Serial.print(F("failed, code "));
    Serial.println(state);
  }

  // wait for a second before transmitting again
  delay(1000);
}

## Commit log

2021-07-21 Remove old files. Add ignore.
    [MicroMod-LoRa-1W-Function-Board-Waterfall.brd, MicroMod-LoRa-1W-Function-Board-Waterfall.sch]
2021-09-07 Adding panel files
    [MicroMod-LoRa-1W-Function-Board-Panel.GBL, MicroMod-LoRa-1W-Function-Board-Panel.GBO, MicroMod-LoRa-1W-Function-Board-Panel.GBP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]
2021-09-20 Fix power control circuit. Add example sketch. Add x02 production panels.
    [MicroMod-LoRa-1W-Function-Board-Panel.GBL, MicroMod-LoRa-1W-Function-Board-Panel.GBO, MicroMod-LoRa-1W-Function-Board-Panel.GBS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]
2021-09-23 Add WP access to card edge.
    [MicroMod-LoRa-1W-Function-Board.brd, MicroMod-LoRa-1W-Function-Board.sch]
2021-09-23 Update version to v10.
    [MicroMod-LoRa-1W-Function-Board-Panel.brd, MicroMod-LoRa-1W-Function-Board.brd, MicroMod-LoRa-1W-Function-Board.sch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]
2021-11-01 Add SMA center pin. Increase panel gap to facilitate center pin. PCB is still v10.
    [MicroMod-LoRa-1W-Function-Board-Panel.GBL, MicroMod-LoRa-1W-Function-Board-Panel.GBO, MicroMod-LoRa-1W-Function-Board-Panel.GBS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]
2021-11-11 Updates the design to use the Micromod-function device in the official SFE Eagle Libs
    [MicroMod-LoRa-1W-Function-Board.brd, MicroMod-LoRa-1W-Function-Board.sch]
2021-11-11 Update README.md
    Added in supported Arduino libraries and hardware datasheets

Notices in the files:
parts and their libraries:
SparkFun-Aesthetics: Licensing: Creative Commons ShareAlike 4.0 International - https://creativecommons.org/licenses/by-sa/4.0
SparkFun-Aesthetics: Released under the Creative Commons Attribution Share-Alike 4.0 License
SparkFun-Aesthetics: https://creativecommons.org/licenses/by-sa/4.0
